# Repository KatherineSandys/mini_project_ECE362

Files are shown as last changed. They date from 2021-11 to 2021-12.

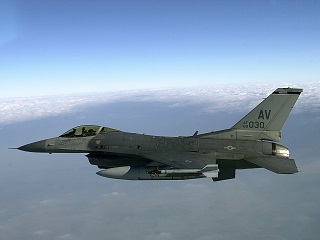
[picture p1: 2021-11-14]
f16.jpg

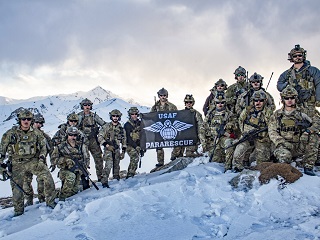
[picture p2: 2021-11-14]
pj.jpg

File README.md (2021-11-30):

# ECE362_Mini_Project

# Submission 2:

## Internal Peripherals: ADC DAC GPIO SPI I2C

## External Peripherals: Analog SPI I2C

## What are you making?

### Splitting project description into describing the physical hardware, and then what it will be doing.

### Hardware Description:
ILI9341 driven 320x240 3.5" TFT Display controller via SPI.
I2C button matrix (Adafruit Product ID 1616, Trellis 4x4 Keypad) with internal LEDs. LEDs are controlled independently of whether buttons are pushed or not. Button state can be read via I2C, and LED state written via I2C.
Touchscreen on top of TFT: Resistive touchscreen overlay, read via 2 ADC channels giving XY coordinates of touch. calibrated via mapping recorded touch points to position user was told to press on the LCD screen (this is the standard way to calibrate these). Some GPIO used to control additional control signals such as D/C line.
(Tentative, will use if time allows for game menu, otherwise will use button matrix)
-Note- both display and keypad matrix are already owned by a team member and don't need to be purchased.
Audio output: Simple audio output via circuitry used in class to headphones. Will use DAC along with DMA to output music during gameplay.

### Operational Description:
A memory game using buttons. The screen will show you the buttons that need to be pressed along with the corresponding buttons lighting up. 
The screen will show what order each needs to be pressed in by superimposing a number on the representation of the buttons on the screen. 
The screen will only show these details for a short period of time, during which the player must memorize this sequence to be able to win. 
Once the screen stops showing the order and the buttons, the user must then press the buttons in the correct order. 
They have an unlimited amount of time to do so. The more buttons pressed and more sequences that they have been through, the higher the score will be.
Once the display has stopped showing what buttons should be pressed, it will display points, a count-up timer, and a representation of what buttons are currently neing pressed.
Of course, Tetris music will be played during operation for the nice ambiance it has.

## How will you demonstrate it?
The game will be played with music in the background.
The aim is to score as many points possible as you complete the game.
As you press the buttons in the correct order for a given problem the score will increase.
If you do not press the correct buttons in the correct order you do not achieve any remaining points for that level.

## What are the criteria for a successful project?

### Hardware requirements:
full control over contents of display
touchscreen properly calibrated, touch points properly map to intended location of press on the LCD.
no visible delay between pressing of keypad and any requisite lighting of keys.
audible audio, with no unpleasant crackles or pops caused by software delay.

### Software
Points are only awarded for correct gameplay, i.e. only when buttons are pressed in the sequence directed.
Display properly shows the buttons to be pressed as well as the sequence in which they should be pressed.
LEDs on keyad light when sequence is shown.

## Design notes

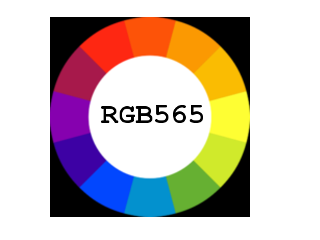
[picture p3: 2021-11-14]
colorpallete.png

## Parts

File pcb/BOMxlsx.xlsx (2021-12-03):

Id | Designator | Package | Quantity | Designation | Supplier and ref | Column1 | _1
1 | MOUNT,MOUNT | MountingHole_3.2mm_M3 | 2 | MountingHole_3.2mm_M3
2 | J7 | microSD_HC_Wuerth_693072010801 | 1 | Micro_SD_Card
3 | J2 | PinSocket_1x04_P2.54mm_Vertical | 1 | Audio
4 | C10 | C_0805_2012Metric_Pad1.15x1.40mm_HandSolder | 1 | 1uF
5 | U2 | LQFP-64_10x10mm_P0.5mm | 1 | STM32F091RCTx
6 | J3 | IDC-Header_2x05_P2.54mm_Vertical | 1 | Conn_02x05_Odd_Even
7 | U1 | SOT-223-3_TabPin2 | 1 | LD1117S33TR_SOT223
8 | R5,R4 | R_0805_2012Metric_Pad1.15x1.40mm_HandSolder | 2 | 470
9 | C20,C21 | C_0805_2012Metric_Pad1.15x1.40mm_HandSolder | 2 | 0.1uF
10 | C1,C2 | C_0805_2012Metric_Pad1.15x1.40mm_HandSolder | 2 | 22uF
11 | J9 | PinHeader_1x04_P2.54mm_Vertical | 1 | Keypad
12 | X1 | ECX-.327-CDX-1293 | 1 | 32.768kHz(12.5pF)
13 | SW1 | SW_SPST_PTS645 | 1 | SW_Push
14 | X2 | Crystal_SMD_3225-4Pin_3.2x2.5mm | 1 | 8MHz(20pF)
15 | R10,R3 | R_0805_2012Metric_Pad1.15x1.40mm_HandSolder | 2 | 100K
16 | R2 | R_0805_2012Metric_Pad1.15x1.40mm_HandSolder | 1 | 1k
17 | R1 | R_0805_2012Metric_Pad1.15x1.40mm_HandSolder | 1 | 5.1k
18 | FB1 | L_0805_2012Metric_Pad1.15x1.40mm_HandSolder | 1 | Ferrite Bead
19 | C12,C13 | C_0805_2012Metric_Pad1.15x1.40mm_HandSolder | 2 | 12pF
20 | R11 | R_0805_2012Metric_Pad1.15x1.40mm_HandSolder | 1 | 390
21 | C14,C15 | C_0805_2012Metric_Pad1.15x1.40mm_HandSolder | 2 | 20pF
22 | C9,C5,C4,C7,C6,C3,C11,C8 | C_0805_2012Metric_Pad1.15x1.40mm_HandSolder | 8 | .1uF
23 | LD1 | LED_0805_2012Metric | 1 | LED_Red
24 | LD2 | LED_0805_2012Metric | 1 | LED_Green
25 | D2,D3 | D_SOD-323 | 2 | BAT60JFILM
26 | C16,C17,C18,C19 | C_0805_2012Metric_Pad1.15x1.40mm_HandSolder | 4 | 10uF
27 | J1 | USB_Micro-B_Molex_47346-0001 | 1 | USB_B_Micro
28 | J6 | PinHeader_1x06_P2.54mm_Vertical | 1 | UART
29 | J8 | PinHeader_1x06_P2.54mm_Vertical | 1 | LCD
30 | J10 | PinHeader_1x04_P2.54mm_Vertical | 1 | Touch
31 | R6 | R_0805_2012Metric_Pad1.15x1.40mm_HandSolder | 1 | 10K

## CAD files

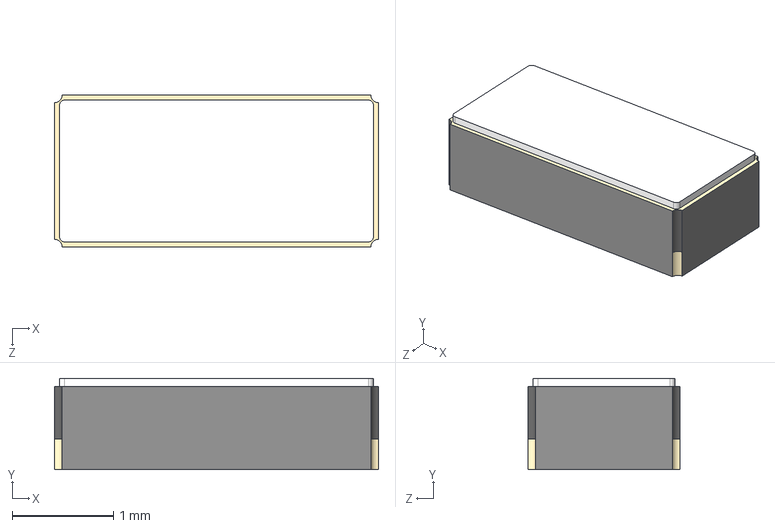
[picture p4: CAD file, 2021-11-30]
pcb/models/ECX-.327-CDX-1293.step
3.20 x 0.9 x 1.50 mm

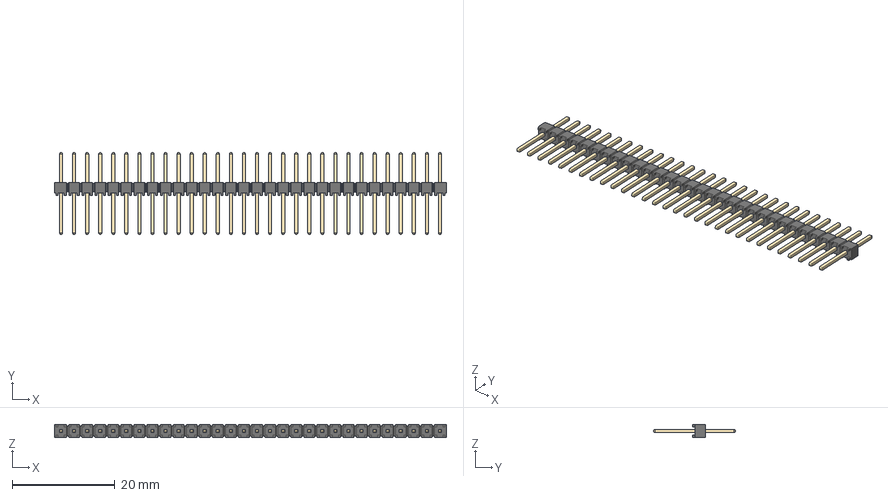
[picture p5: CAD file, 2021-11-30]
pcb/models/HTSW-130-22-T-S.FCStd
76.2 x 16.0 x 2.49 mm
_HTSW-130-22-T-S_body
_T-1S6-15-HTSW-1--22-30-S

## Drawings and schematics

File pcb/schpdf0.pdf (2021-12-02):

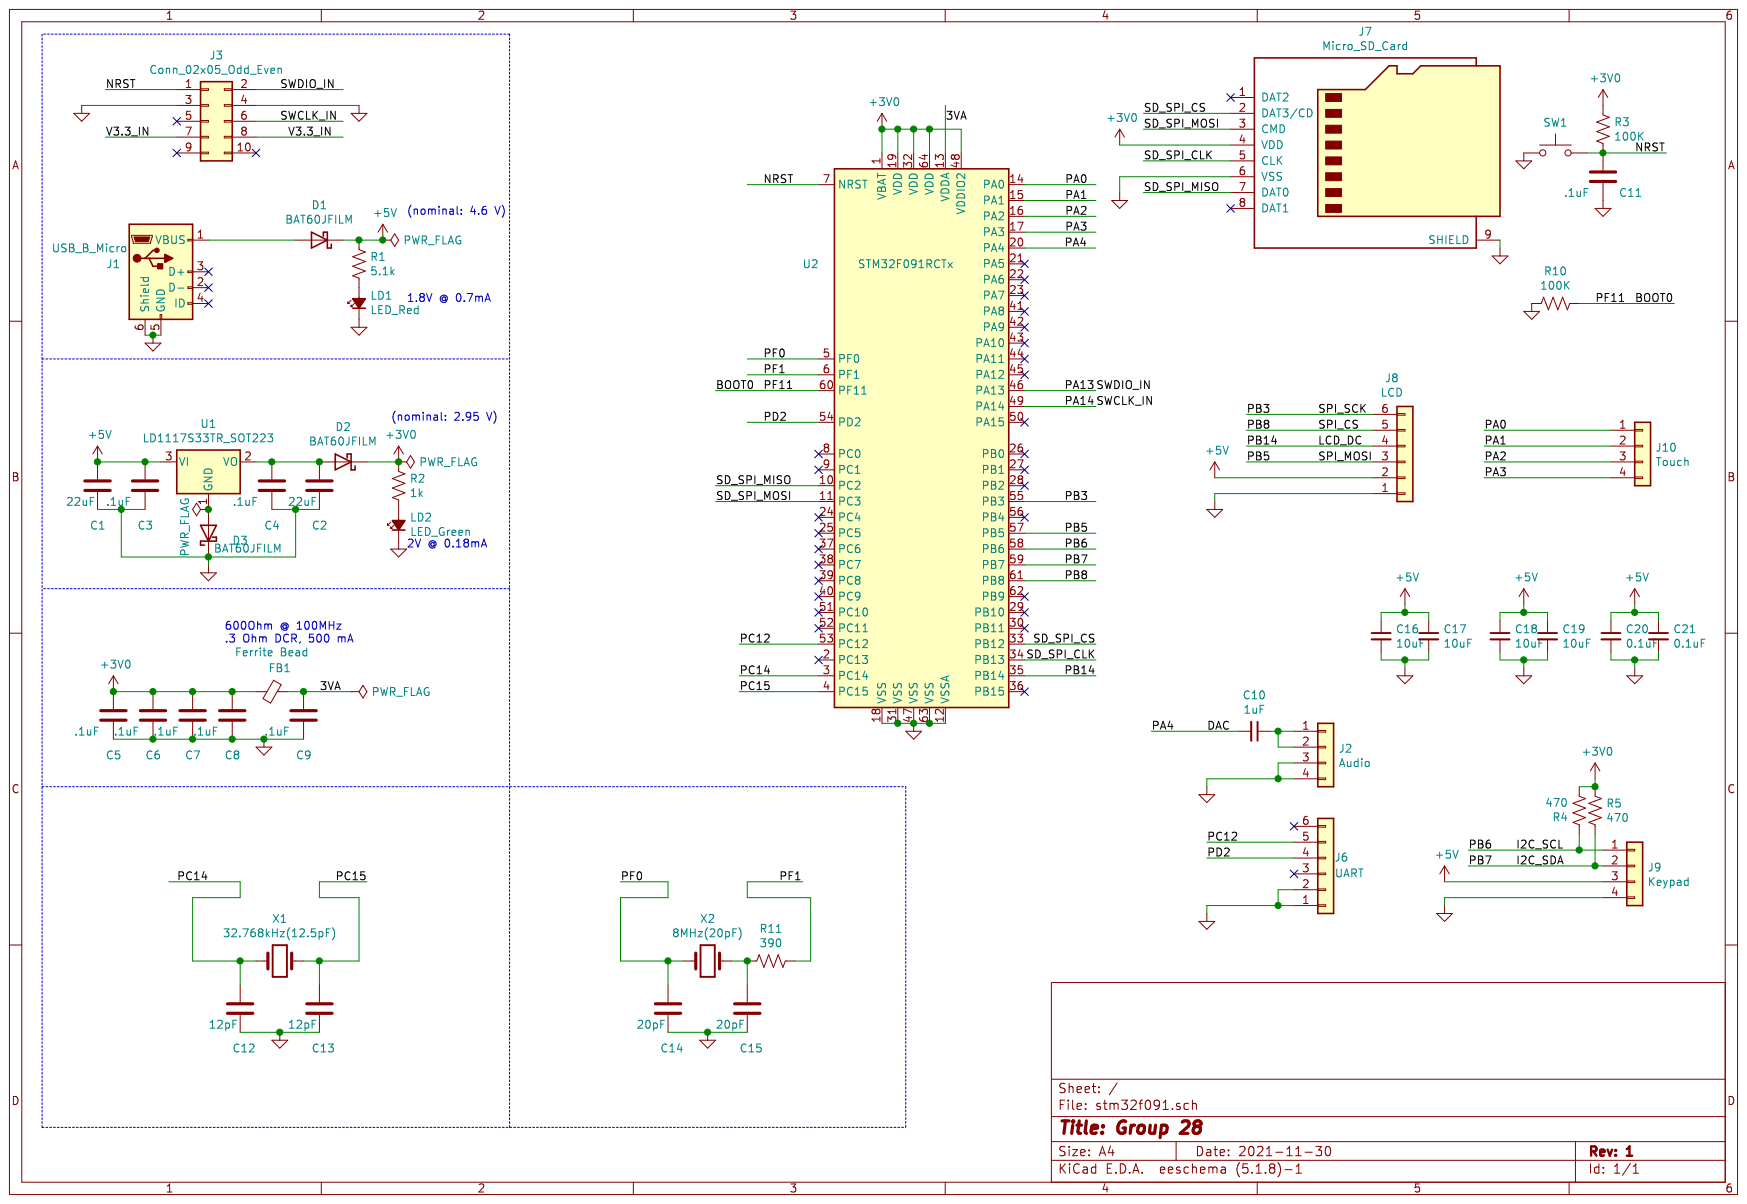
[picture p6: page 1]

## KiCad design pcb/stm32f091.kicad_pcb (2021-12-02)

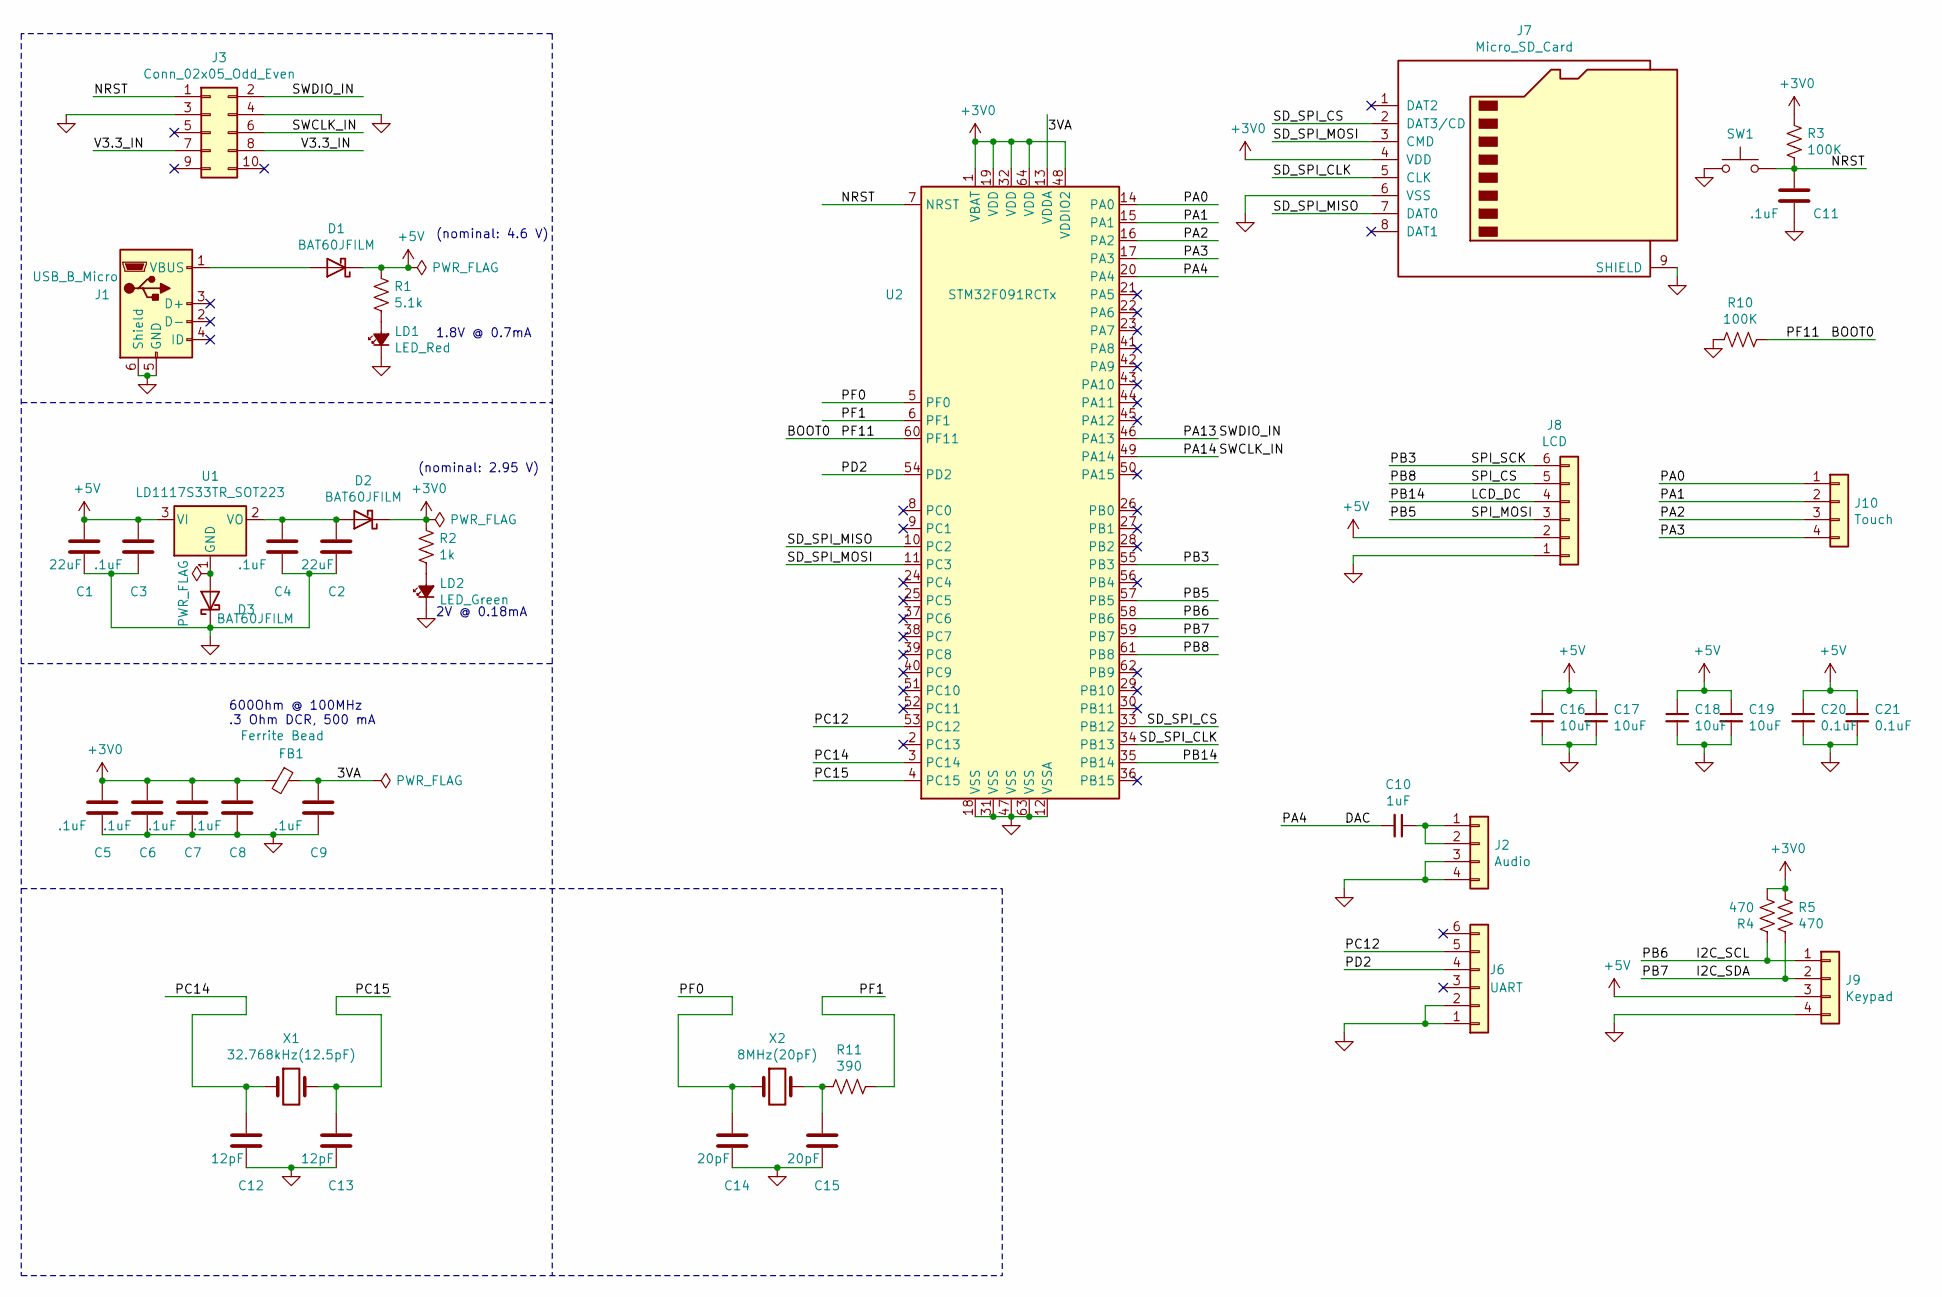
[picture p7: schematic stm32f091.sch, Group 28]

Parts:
C1, C2: 22uF; C_0805_2012Metric_Pad1.15x1.40mm_HandSolder
C3, C4, C5, C6, C7, C8, C9, C11: .1uF; C_0805_2012Metric_Pad1.15x1.40mm_HandSolder
C10: 1uF; C_0805_2012Metric_Pad1.15x1.40mm_HandSolder
C12, C13: 12pF; C_0805_2012Metric_Pad1.15x1.40mm_HandSolder
C14, C15: 20pF; C_0805_2012Metric_Pad1.15x1.40mm_HandSolder
C16, C17, C18, C19: 10uF; C_0805_2012Metric_Pad1.15x1.40mm_HandSolder
C20, C21: 0.1uF; C_0805_2012Metric_Pad1.15x1.40mm_HandSolder
D1, D2, D3: BAT60JFILM; D_SOD-323
FB1: Ferrite Bead; L_0805_2012Metric_Pad1.15x1.40mm_HandSolder
J1: USB_B_Micro; USB_Micro-B_Molex_47346-0001
J2: Audio; PinSocket_1x04_P2.54mm_Vertical
J3: Conn_02x05_Odd_Even; IDC-Header_2x05_P2.54mm_Vertical
J6: UART; PinHeader_1x06_P2.54mm_Vertical
J7: Micro_SD_Card; microSD_HC_Wuerth_693072010801
J8: LCD; PinHeader_1x06_P2.54mm_Vertical
J9: Keypad; PinHeader_1x04_P2.54mm_Vertical
J10: Touch; PinHeader_1x04_P2.54mm_Vertical
LD1: LED_Red; LED_0805_2012Metric
LD2: LED_Green; LED_0805_2012Metric
R1: 5.1k; R_0805_2012Metric_Pad1.15x1.40mm_HandSolder
R2: 1k; R_0805_2012Metric_Pad1.15x1.40mm_HandSolder
R3, R10: 100K; R_0805_2012Metric_Pad1.15x1.40mm_HandSolder
R4, R5: 470; R_0805_2012Metric_Pad1.15x1.40mm_HandSolder
R11: 390; R_0805_2012Metric_Pad1.15x1.40mm_HandSolder; LCSC C17477
SW1: SW_Push; SW_SPST_PTS645
U1: LD1117S33TR_SOT223; SOT-223-3_TabPin2
U2: STM32F091RCTx; LQFP-64_10x10mm_P0.5mm
X1: 32.768kHz(12.5pF); ECX-.327-CDX-1293
X2: 8MHz(20pF); Crystal_SMD_3225-4Pin_3.2x2.5mm

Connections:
+3V0: C5.1, C6.1, C7.1, C8.1, D2.1 (K), FB1.2, J7.4 (VDD), R2.1, R3.1, R4.2, R5.1, U2.1 (VBAT), U2.19 (VDD), U2.32 (VDD), U2.48 (VDDIO2), U2.64 (VDD); also elsewhere on the board
+5V: C1.1, C3.1, C16.1, C17.1, C18.1, C19.1, C20.1, C21.1, D1.1 (K), D1.2 (A), J1.1 (VBUS), J8.2, J9.3, R1.1, U1.3 (VI)
/3VA: C9.1, FB1.1, U2.13 (VDDA)
/BOOT0: R10.1, U2.60 (PF11)
/DAC: C10.2, U2.20 (PA4)
/I2C_SCL: J9.1, R4.1, U2.58 (PB6)
/I2C_SDA: J9.2, R5.2, U2.59 (PB7)
/LCD_DC: J8.4, U2.35 (PB14)
/NRST: C11.1, J3.1, R3.2, SW1.2, U2.7 (NRST)
/PA0: J10.1, U2.14 (PA0)
/PA1: J10.2, U2.15 (PA1)
/PA2: J10.3, U2.16 (PA2)
/PA3: J10.4, U2.17 (PA3)
/PA13: J3.2, U2.46 (PA13)
/PA14: J3.6, U2.49 (PA14)
/PB3: J8.6, U2.55 (PB3)
/PB5: J8.3, U2.57 (PB5)
/PB8: J8.5, U2.61 (PB8)
/PC12: J6.5, U2.53 (PC12)
/PC14: C12.1, U2.3 (PC14), X1.1
/PC15: C13.1, U2.4 (PC15), X1.2
/PD2: J6.4, U2.54 (PD2)
/PF0: C14.1, U2.5 (PF0), X2.1
/PF1: R11.1, U2.6 (PF1)
/SD_SPI_CLK: J7.5 (CLK), U2.34 (PB13)
/SD_SPI_CS: J7.2 (DAT3/CD), U2.33 (PB12)
/SD_SPI_MISO: J7.7 (DAT0), U2.10 (PC2); also elsewhere on the board
/SD_SPI_MOSI: J7.3 (CMD), U2.11 (PC3)
/V3.3_IN: J3.7, J3.8
GND: C1.2, C2.2, C3.2, C4.2, C5.2, C6.2, C7.2, C8.2, C9.2, C11.2, C12.2, C13.2, C14.2, C15.2, C16.2, C17.2, C18.2, C19.2, C20.2, C21.2, D3.1 (K), J1.5 (GND), J1.6 (Shield), J2.3, J2.4, J3.3, J3.4, J6.1, J6.2, J7.6 (VSS), J7.9 (SHIELD), J8.1, J9.4, LD1.1 (K), LD2.1 (K), R10.2, SW1.1, U2.12 (VSSA), U2.18 (VSS), U2.31 (VSS), U2.47 (VSS), U2.63 (VSS)
unnamed: C2.1, C4.1, D2.2 (A), U1.2 (VO)
unnamed: C10.1, J2.1, J2.2
unnamed: C15.1, R11.2, X2.2
unnamed: D3.2 (A), U1.1 (GND)
unnamed: LD1.2 (A), R1.2
unnamed: LD2.2 (A), R2.2

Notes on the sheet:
1.8V @ 0.7mA
2V @ 0.18mA
600Ohm @ 100MHz .3 Ohm DCR, 500 mA
(nominal: 4.6 V)
(nominal: 2.95 V)

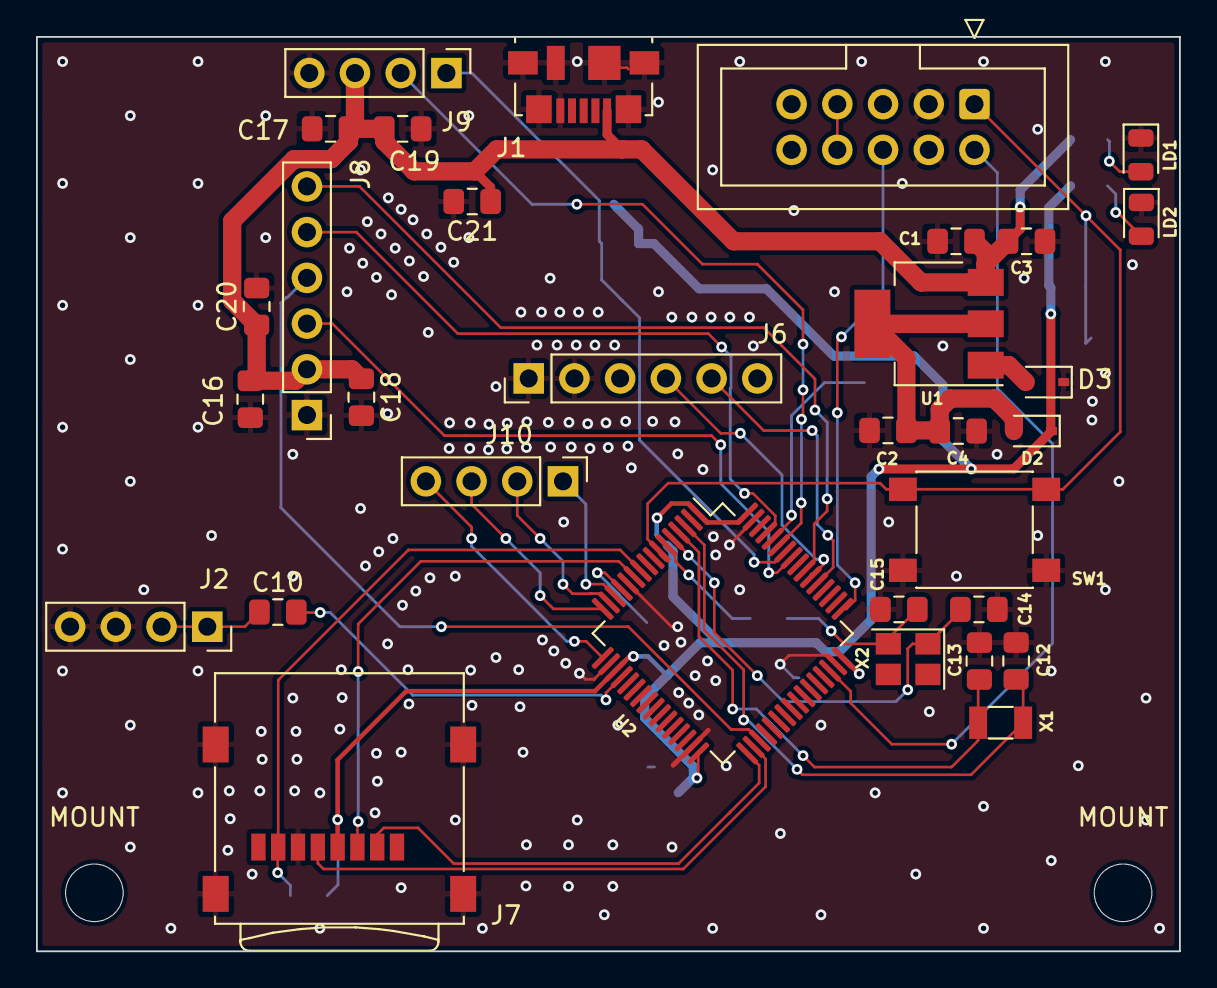
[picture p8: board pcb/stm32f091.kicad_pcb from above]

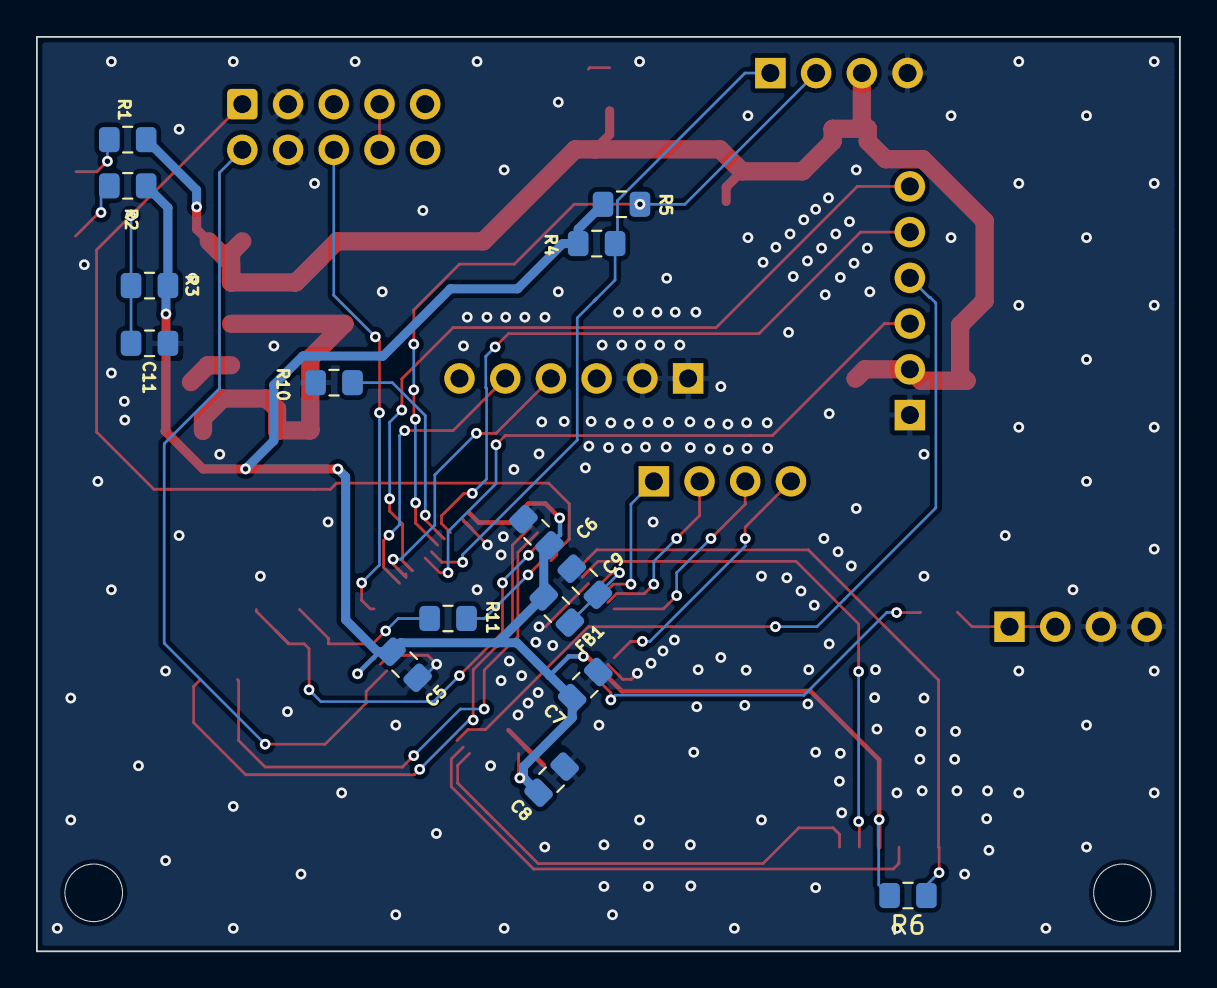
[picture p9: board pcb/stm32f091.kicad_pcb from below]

Board: 2 copper layers, 63.5 x 50.8 mm, 49 parts (15 on the bottom side), 36 nets.

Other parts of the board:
MOUNT: MountingHole_3.2mm_M3
MOUNT#2: MountingHole_3.2mm_M3
R6: 10K; R_0805_2012Metric_Pad1.15x1.40mm_HandSolder

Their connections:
+3V0: R6.2; also elsewhere on the board
/SD_SPI_MISO: R6.1; also elsewhere on the board

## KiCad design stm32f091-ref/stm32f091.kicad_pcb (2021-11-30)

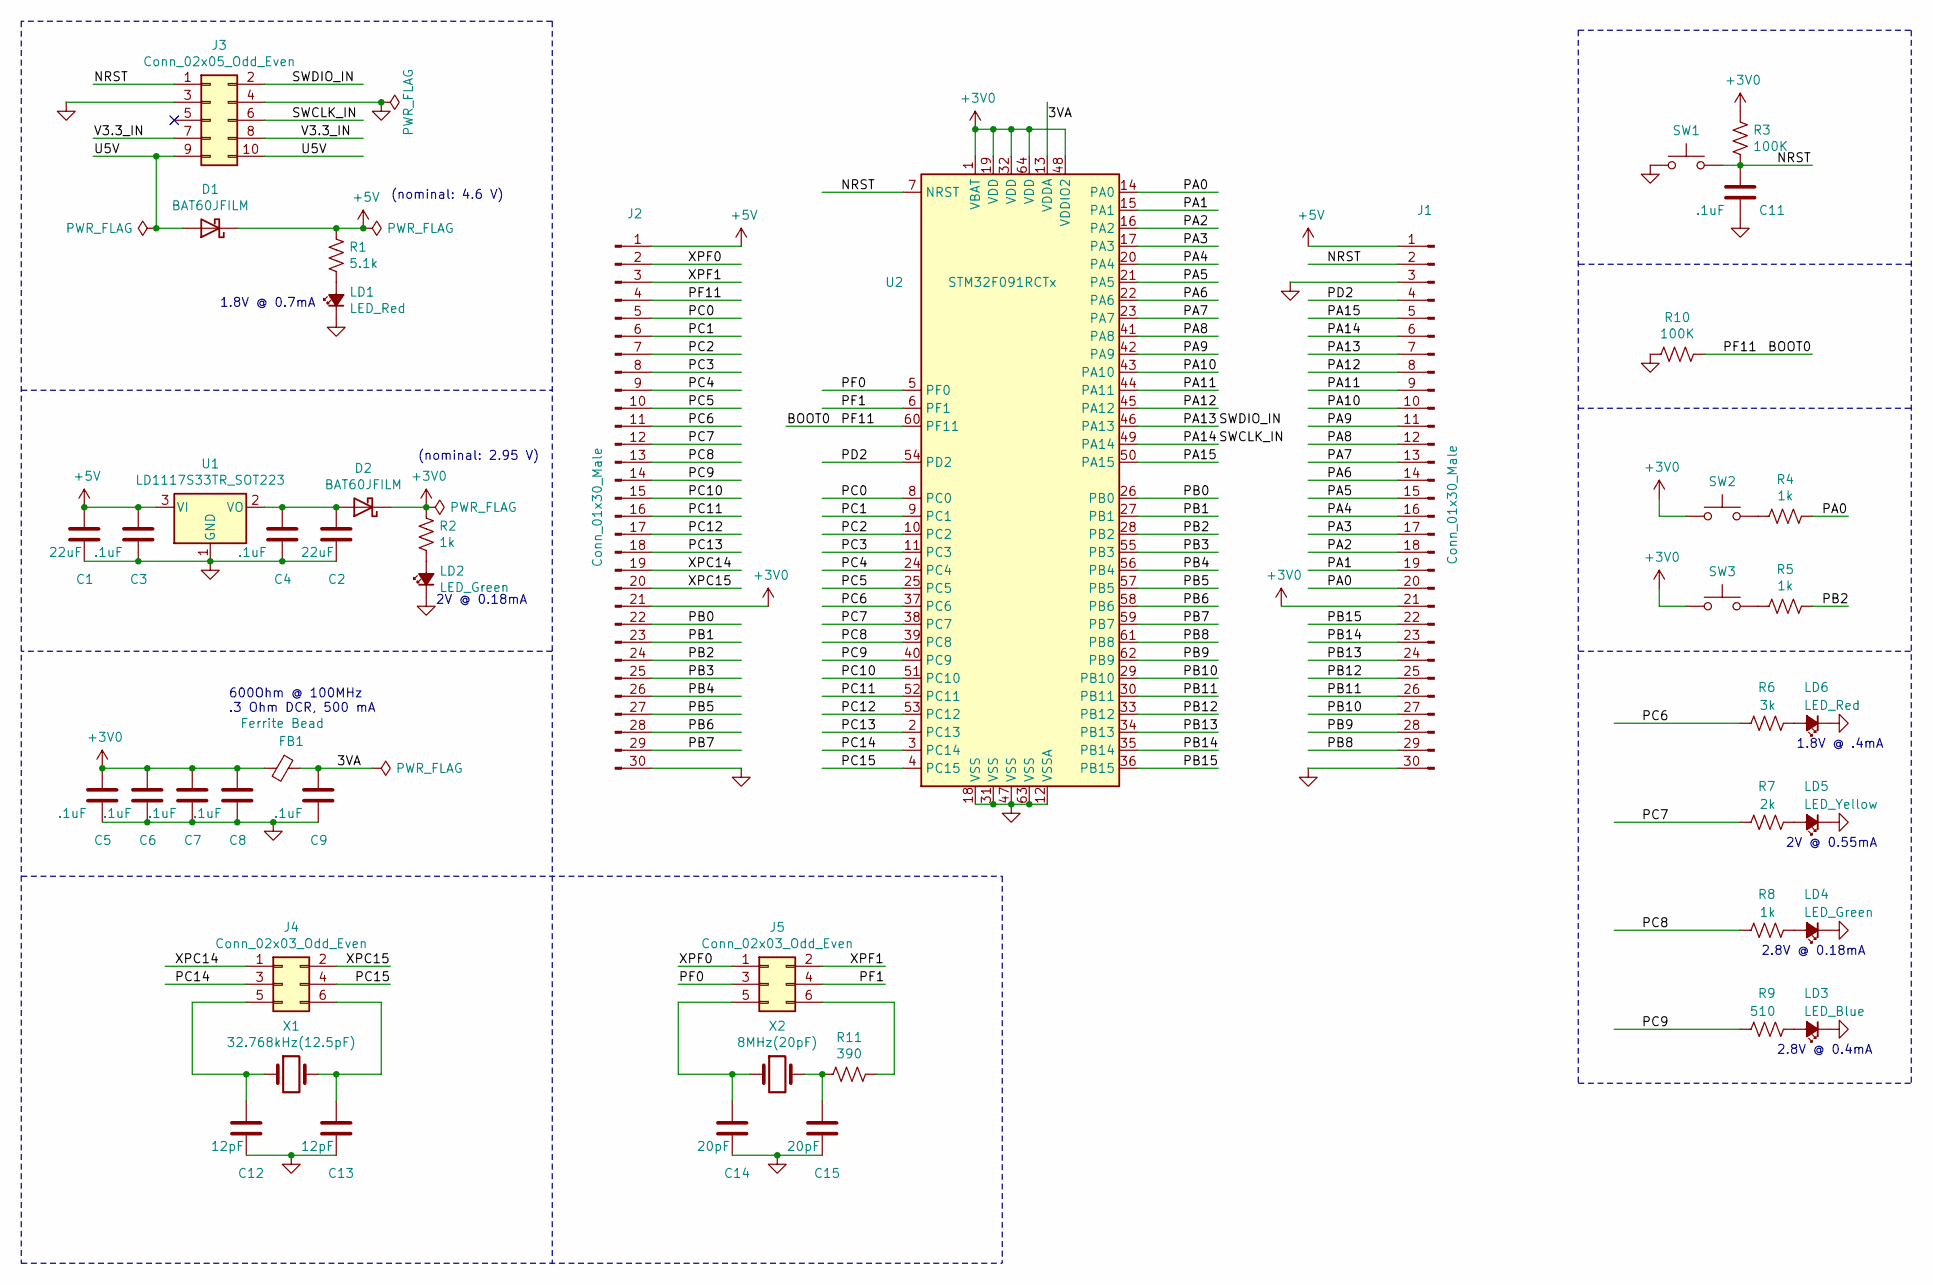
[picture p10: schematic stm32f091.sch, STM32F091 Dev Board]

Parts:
C1, C2: 22uF; C_0805_2012Metric_Pad1.15x1.40mm_HandSolder
C3, C4, C5, C6, C7, C8, C9, C11: .1uF; C_0805_2012Metric_Pad1.15x1.40mm_HandSolder
C12, C13: 12pF; C_0805_2012Metric_Pad1.15x1.40mm_HandSolder
C14, C15: 20pF; C_0805_2012Metric_Pad1.15x1.40mm_HandSolder
D1, D2: BAT60JFILM; D_SOD-323
FB1: Ferrite Bead; L_0805_2012Metric_Pad1.15x1.40mm_HandSolder
J1, J2: Conn_01x30_Male; HTSW-130-22-T-S
J3: Conn_02x05_Odd_Even; IDC-Header_2x05_P2.54mm_Vertical
J4, J5: Conn_02x03_Odd_Even; PinHeader_2x03_P1.27mm_Vertical
LD1, LD6: LED_Red; LED_0805_2012Metric
LD2, LD4: LED_Green; LED_0805_2012Metric
LD3: LED_Blue; LED_0805_2012Metric
LD5: LED_Yellow; LED_0805_2012Metric
R1: 5.1k; R_0805_2012Metric_Pad1.15x1.40mm_HandSolder
R2, R4, R5, R8: 1k; R_0805_2012Metric_Pad1.15x1.40mm_HandSolder
R3, R10: 100K; R_0805_2012Metric_Pad1.15x1.40mm_HandSolder
R6: 3k; R_0805_2012Metric_Pad1.15x1.40mm_HandSolder
R7: 2k; R_0805_2012Metric_Pad1.15x1.40mm_HandSolder
R9: 510; R_0805_2012Metric_Pad1.15x1.40mm_HandSolder
R11: 390; R_0805_2012Metric_Pad1.15x1.40mm_HandSolder; LCSC C17477
SW1, SW2, SW3: SW_Push; SW_SPST_PTS645
U1: LD1117S33TR_SOT223; SOT-223-3_TabPin2
U2: STM32F091RCTx; LQFP-64_10x10mm_P0.5mm
X1: 32.768kHz(12.5pF); ECX-.327-CDX-1293
X2: 8MHz(20pF); Crystal_SMD_3225-4Pin_3.2x2.5mm

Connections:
+3V0: C5.1, C6.1, C7.1, C8.1, D2.1 (K), FB1.2, J1.21, J2.21, R2.1, R3.1, SW2.1, SW3.1, U2.1 (VBAT), U2.19 (VDD), U2.32 (VDD), U2.48 (VDDIO2), U2.64 (VDD)
+5V: C1.1, C3.1, D1.1 (K), J1.1, J2.1, R1.1, U1.3 (VI)
/3VA: C9.1, FB1.1, U2.13 (VDDA)
/BOOT0: J2.4, R10.1, U2.60 (PF11)
/NRST: C11.1, J1.2, J3.1, R3.2, SW1.2, U2.7 (NRST)
/PA0: J1.20, R4.1, U2.14 (PA0)
/PA1: J1.19, U2.15 (PA1)
/PA2: J1.18, U2.16 (PA2)
/PA3: J1.17, U2.17 (PA3)
/PA4: J1.16, U2.20 (PA4)
/PA5: J1.15, U2.21 (PA5)
/PA6: J1.14, U2.22 (PA6)
/PA7: J1.13, U2.23 (PA7)
/PA8: J1.12, U2.41 (PA8)
/PA9: J1.11, U2.42 (PA9)
/PA10: J1.10, U2.43 (PA10)
/PA11: J1.9, U2.44 (PA11)
/PA12: J1.8, U2.45 (PA12)
/PA13: J1.7, J3.2, U2.46 (PA13)
/PA14: J1.6, J3.6, U2.49 (PA14)
/PA15: J1.5, U2.50 (PA15)
/PB0: J2.22, U2.26 (PB0)
/PB1: J2.23, U2.27 (PB1)
/PB2: J2.24, R5.1, U2.28 (PB2)
/PB3: J2.25, U2.55 (PB3)
/PB4: J2.26, U2.56 (PB4)
/PB5: J2.27, U2.57 (PB5)
/PB6: J2.28, U2.58 (PB6)
/PB7: J2.29, U2.59 (PB7)
/PB8: J1.29, U2.61 (PB8)
/PB9: J1.28, U2.62 (PB9)
/PB10: J1.27, U2.29 (PB10)
/PB11: J1.26, U2.30 (PB11)
/PB12: J1.25, U2.33 (PB12)
/PB13: J1.24, U2.34 (PB13)
/PB14: J1.23, U2.35 (PB14)
/PB15: J1.22, U2.36 (PB15)
/PC0: J2.5, U2.8 (PC0)
/PC1: J2.6, U2.9 (PC1)
/PC2: J2.7, U2.10 (PC2)
/PC3: J2.8, U2.11 (PC3)
/PC4: J2.9, U2.24 (PC4)
/PC5: J2.10, U2.25 (PC5)
/PC6: J2.11, R6.2, U2.37 (PC6)
/PC7: J2.12, R7.2, U2.38 (PC7)
/PC8: J2.13, R8.2, U2.39 (PC8)
/PC9: J2.14, R9.2, U2.40 (PC9)
/PC10: J2.15, U2.51 (PC10)
/PC11: J2.16, U2.52 (PC11)
/PC12: J2.17, U2.53 (PC12)
/PC13: J2.18, U2.2 (PC13)
/PC14: J4.3, U2.3 (PC14)
/PC15: J4.4, U2.4 (PC15)
/PD2: J1.4, U2.54 (PD2)
/PF0: J5.3, U2.5 (PF0)
/PF1: J5.4, U2.6 (PF1)
/U5V: D1.2 (A), J3.9, J3.10
/V3.3_IN: J3.7, J3.8
/XPC14: J2.19, J4.1
/XPC15: J2.20, J4.2
/XPF0: J2.2, J5.1
/XPF1: J2.3, J5.2
GND: C1.2, C2.2, C3.2, C4.2, C5.2, C6.2, C7.2, C8.2, C9.2, C11.2, C12.2, C13.2, C14.2, C15.2, J1.3, J1.30, J2.30, J3.3, J3.4, LD1.1 (K), LD2.1 (K), LD3.1 (K), LD4.1 (K), LD5.1 (K), LD6.1 (K), R10.2, SW1.1, U1.1 (GND), U2.12 (VSSA), U2.18 (VSS), U2.31 (VSS), U2.47 (VSS), U2.63 (VSS)
unnamed: C2.1, C4.1, D2.2 (A), U1.2 (VO)
unnamed: C12.1, J4.5, X1.1
unnamed: C13.1, J4.6, X1.2
unnamed: C14.1, J5.5, X2.1
unnamed: C15.1, R11.2, X2.2
unnamed: J5.6, R11.1
unnamed: LD1.2 (A), R1.2
unnamed: LD2.2 (A), R2.2
unnamed: LD3.2 (A), R9.1
unnamed: LD4.2 (A), R8.1
unnamed: LD5.2 (A), R7.1
unnamed: LD6.2 (A), R6.1
unnamed: R4.2, SW2.2
unnamed: R5.2, SW3.2

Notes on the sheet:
1.8V @ 0.7mA
2V @ 0.18mA
2.8V @ 0.18mA
2.8V @ 0.4mA
600Ohm @ 100MHz .3 Ohm DCR, 500 mA
1.8V @ .4mA
2V @ 0.55mA
(nominal: 4.6 V)
(nominal: 2.95 V)

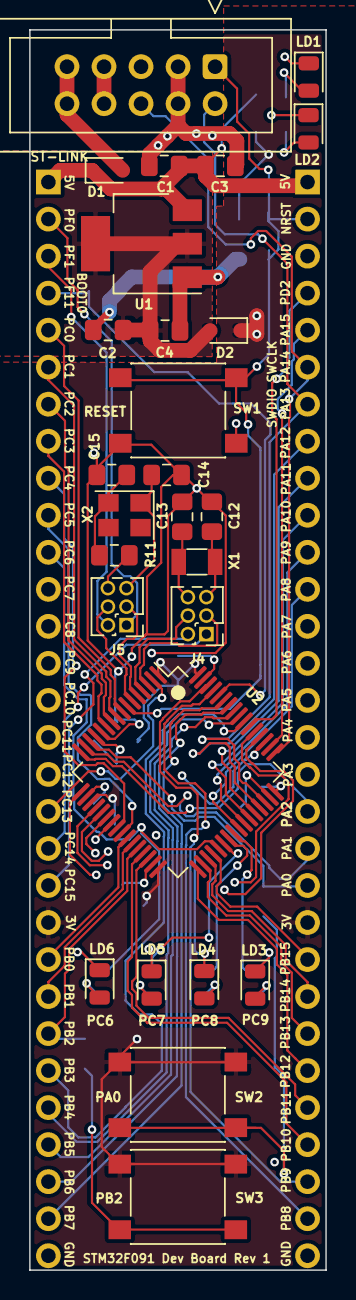
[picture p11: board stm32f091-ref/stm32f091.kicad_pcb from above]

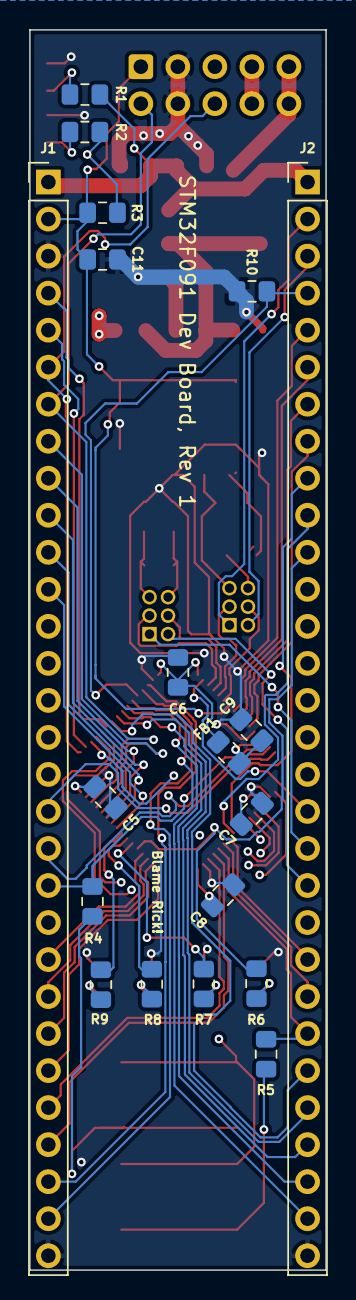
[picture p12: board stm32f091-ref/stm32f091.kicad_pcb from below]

Board: 4 copper layers, 20.3 x 85.1 mm, 46 parts (19 on the bottom side), 77 nets.

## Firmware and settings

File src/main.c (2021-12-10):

#include "stm32f0xx.h"
#include <string.h> // for memset() declaration
#include <math.h>   // for MA_PI
#include "keypad.h"
#include "lcd.h"
#include "graphics.h"
#include "images/pj.h"
#include "images/colorpallete.h"
#include "game.h"
#include "keypad.h"
#include "touch.h"
#include "audio.h"

int main(void)
{
    read_song();

    /*for(;;)
    {

    }*/
    wait_ms(1);
    initKeypad();

    wait_ms(1);
    initLCD();
    wait_ms(1);
    LCD_Clear(WHITE);

    init_touch();

    /*for (;;)
    {
    	struct point* p = get_touch();

    	LCD_DrawFillRectangle(p->x, p->y, p->x+5, p->y+5, BLACK);
    }*/

    for (;;)
    {
        game();
        game_over();
    }
}

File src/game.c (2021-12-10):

#include "game.h"
#include "lcd.h"
#include <string.h>
#include "keypad.h"
#include "graphics.h"
#include "images/font_arcade.h"
#include "touch.h"

node * head = NULL;
int max_time_ms;
int score;

int curr_counter = -1;
bool active = false;
int curr_width = 240;
float rate = 0;
bool hard = false;

node * add_node() {
    node * n = malloc(sizeof(*n));
    n->id = random() % 15;
    n->next = NULL;
    return n;
}

void draw_rectangle_grid() {
    int square_side = 180 / 2;
    int inner = square_side / 2;
    LCD_DrawRectangle(320/2 - square_side, 240/2 - square_side, 320/2 + square_side, 240/2 + square_side, RED);
    for(int i = 0; i < 4; i++) {
        for(int j = 0; j < 4; j++) {
            LCD_DrawRectangle(320/2 - square_side + i * inner, 240/2 - square_side + j * inner, 320/2 - square_side + (i + 1) * inner, 240/2 - square_side + (j + 1) * inner, RED);
        }
    }
}

void light_grid_rectangle(int id) {
    int square_side = 180 / 2;
    int inner = square_side / 2;
    int x = id / 4;
    int y = id % 4;

    LCD_DrawFillRectangle(320/2 - square_side + x * inner, 240/2 - square_side + (3-y) * inner, 320/2 - square_side + (x + 1) * inner, 240/2 - square_side + (3 - y + 1) * inner, RED);
}

void clear_grid_rectangle(int id) {
    int square_side = 180 / 2;
    int inner = square_side / 2;
    int x = id / 4;
    int y = id % 4;

    LCD_DrawFillRectangle(320/2 - square_side + x * inner, 240/2 - square_side + (3-y) * inner, 320/2 - square_side + (x + 1) * inner, 240/2 - square_side + (3 - y + 1) * inner, WHITE);
    LCD_DrawRectangle(320/2 - square_side + x * inner, 240/2 - square_side + (3-y) * inner, 320/2 - square_side + (x + 1) * inner, 240/2 - square_side + (3 - y + 1) * inner, RED);

}

void display_id(int id) {
    int delay = hard ? 100 : 400;
    light_grid_rectangle(id);
    setLED(id);
    wait_ms(delay);
    clrLED(id);
    clear_grid_rectangle(id);
    wait_ms(delay);
}

void display_sequence() {
    draw_rectangle_grid();
    node * l = head;
    while(l->next != NULL) {
        display_id(l->id);
        l = l->next;
    }
    l->next = add_node();
    display_id(l->id);
    l = l->next;
    display_id(l->id);
    //empty buffer in case of accidental clicks during display
    while(get_keypress() != -1){
        wait_ms(15);
    }
}

void free_list() {
    while(head != NULL) {
        node * temp = head;
        head = head -> next;
        free(temp);
    }
}

bool read_sequence() {
    node * l = head;
    while (l != NULL && active) {
    	//time expired
    	if (curr_counter >= max_time_ms) return false;

        for(int button = get_keypress(); button != -1; button = get_keypress()) {
            setLED(button);
            wait_ms(150);
            clrLED(button);
            if (button != l->id) {
                free_list();
                return false;
            }
            l = l->next;
        }

    }
    return active ? true : false;
}

void swap_mode() {
    setAllLEDs();
    wait_ms(500);
    clrAllLEDs();
}

void TIM2_IRQHandler() {
    TIM2->SR &= ~TIM_SR_UIF;

    if (curr_counter >= max_time_ms) return;
    curr_counter += 10;
}


void TIM3_IRQHandler() {
    TIM3->SR &= ~TIM_SR_UIF;

    if (curr_counter >= max_time_ms) return;

    //if at a second boundary, draw the digits.
    if (curr_counter % 100 == 0)
    {
    	char time_remaining[5] = {' ', ' ', ' ', ' ', '\0'};
    	int diff = (max_time_ms-curr_counter) / 100;
    	itoa(diff, time_remaining+1, 10);
    	if (diff > 10) {
    	    time_remaining[0] = time_remaining[1];
            time_remaining[1] = '.';
    	}
    	else {
            time_remaining[0] = '.';
    	}

    	//LCD_DrawFillRectangle(320/2-10, 240/2, 320/2 + 100, 180, WHITE);

    	LCD_DrawString(320/2 - 10, 240/2, BLACK, WHITE, time_remaining, 16, 0);

    }

    //must go from 0 to 240 in max_time_ms cycles (this is a 1KHz timer)
    int pixel = (320 * curr_counter) / max_time_ms;

    LCD_DrawFillRectangle(pixel-5, 200+1, pixel, 240-1, RED);

    //curr_counter += 10;
}

void game_over() {
    setAllLEDs();
    LCD_Clear(WHITE);
    LCD_DrawRectangle(10, 10, 320-10, 240-10, RED);
    //LCD_DrawString(120, 240/2 - 16, BLACK, WHITE, "Game Over", 16, 0);
    draw_graphic_string(320/2, 240/2-50, "Game\nOver", &font_arcade);
    char temp[5];
    char score_arr[15] = {'S', 'c', 'o', 'r', 'e', ':', ' '};
    itoa(score, temp, 10);
    strcat(score_arr, temp);
    LCD_DrawString(120, 100, BLACK, WHITE, score_arr, 16, 0);

#define RESTART_RECT_CENTER_X (320/2)
#define RESTART_RECT_CENTER_Y (240/2+40)
#define RESTART_RECT_WIDTH    100
#define RESTART_RECT_HEIGHT   40
#define RESTART_RECT_X0		  (RESTART_RECT_CENTER_X - RESTART_RECT_WIDTH/2)
#define RESTART_RECT_Y0		  (RESTART_RECT_CENTER_Y - RESTART_RECT_HEIGHT/2)
#define RESTART_RECT_X1		  (RESTART_RECT_CENTER_X + RESTART_RECT_WIDTH/2)
#define RESTART_RECT_Y1		  (RESTART_RECT_CENTER_Y + RESTART_RECT_HEIGHT/2)

    LCD_DrawRectangle(RESTART_RECT_X0, RESTART_RECT_Y0, RESTART_RECT_X1, RESTART_RECT_Y1, RED);
    LCD_DrawString(320/20+110, 240/2+30, BLACK, WHITE, "Try Again", 16, 0);
    for(Point * p = get_touch(); (p->x > RESTART_RECT_X1) || (p->x < RESTART_RECT_X0) || (p->y % 240 > RESTART_RECT_Y1) || (p->y % 240 < RESTART_RECT_Y0); p = get_touch()) {
        wait_ms(20);
    }
    clrAllLEDs();
}

void display_score_corner() {
    //display score
    char temp[5];
    char score_arr[15] = {'S', 'c', 'o', 'r', 'e', ':', ' '};
    itoa(score, temp, 10);
    strcat(score_arr, temp);
    LCD_DrawString(5, 5, BLACK, WHITE, score_arr, 16, 0);
}

void game() {
    //Timer enables
    if (!(RCC->APB1ENR & RCC_APB1ENR_TIM2EN)) {
            RCC->APB1ENR |= RCC_APB1ENR_TIM2EN;
            TIM2->PSC = 480-1;
            TIM2->ARR = 1000-1;
            TIM2->DIER |= TIM_DIER_UIE;
            TIM2->CR1 |= TIM_CR1_CEN;
    }
    if (!(RCC->APB1ENR & RCC_APB1ENR_TIM3EN)) {
           RCC->APB1ENR |= RCC_APB1ENR_TIM3EN;
           TIM3->PSC = 48-1;
           TIM3->ARR = 5000-1;
           TIM3->DIER |= TIM_DIER_UIE;
   }
    //reset in case subsequent game
    score = 0;
    NVIC_EnableIRQ(TIM2_IRQn);
    NVIC_EnableIRQ(TIM3_IRQn); /* (1) */
    while(get_keypress()!=-1);

    LCD_Clear(WHITE);
    LCD_DrawRectangle(10, 10, 320-10, 240-10, BLACK);
    draw_graphic_string(320/2 - 5, 240/2 - 30, "Press any\nkey to start", &font_arcade);

#define EASY_RECT_CENTER_X (90)
#define EASY_RECT_CENTER_Y (160)
#define EASY_RECT_WIDTH    110
#define EASY_RECT_HEIGHT   40
#define EASY_RECT_OUTLINE  5
#define EASY_RECT_X0       (EASY_RECT_CENTER_X - EASY_RECT_WIDTH/2)
#define EASY_RECT_Y0       (EASY_RECT_CENTER_Y - EASY_RECT_HEIGHT/2)
#define EASY_RECT_X1       (EASY_RECT_CENTER_X + EASY_RECT_WIDTH/2)
#define EASY_RECT_Y1       (EASY_RECT_CENTER_Y + EASY_RECT_HEIGHT/2)
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

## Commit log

2021-11-14 mini project starter
    [miniproject Run.cfg]
2021-11-30 added pcb, some new source files
    [ECX-.327-CDX-1293.step, HTSW-130-22-T-S.FCStd, stm32f091.kicad_pcb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]
2021-11-30 Board dimensions
2021-11-30 moved keypad into driver file
    [ECE362_Mini_Project Run.cfg]
2021-11-30 schematic work
    [stm32f091.kicad_pcb, stm32f091.sch]
2021-12-01 schematic complete
    [stm32f091.kicad_pcb, stm32f091.sch]
2021-12-02 keypad drivers complete
2021-12-02 Board Layout
    [stm32f091.kicad_pcb]
2021-12-02 completed pcb
    [stm32f091.kicad_pcb]
2021-12-02 stitched vias
    [stm32f091.kicad_pcb]
2021-12-02 moved vias from under pads, fixed trace widths
    [stm32f091.kicad_pcb]
2021-12-02 added SD_SPI_MISO 10K pullup
    [stm32f091.kicad_pcb]
2021-12-03 workingish game and countdown timer
2021-12-03 added BOM
    [BOMxlsx.xlsx, stm32f091.csv]
2021-12-04 finished first rev of working game logic with LCD and buttons
2021-12-04 more ui and fix same button in row not flashing
    [audio.c, game.c]
2021-12-06 fixed timer delay
2021-12-07 initial try again button
2021-12-07 fixed click on wraparound
    [audio.c]
2021-12-09 complete audio, fixed touch
    [audio.c, game.c, keypad.c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]
